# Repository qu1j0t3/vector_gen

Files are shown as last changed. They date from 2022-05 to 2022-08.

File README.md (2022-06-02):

# Vector generator

Copyright (C) 2017-2022 Toby Thain <toby@telegraphics.com.au>

## Purpose

This circuit is designed to produce X, Y and Z (blanking) signals
for an analog CRT such as an oscilloscope or XY monitor.

It is controlled by a microcontroller using one digital input
and 12 digital outputs. The speed of the microcontroller is not
critical to the design; all timing critical functions are executed
in hardware.

## Output specifications

### Monitors tested

* Tektronix 602, 603, 604, 606

## Graphic capabilities

* Positioning to 12 bit precision
* Lines (approx 20,000 short-medium vectors per second[1];
  10,000 "long" vectors per second[2])
  - dashed lines (dashing defined by 30 bit vector)
  - speed can be increased further by adjusting integrator passives
    and software optimisations
* Points (37,000-60,000 per second at 0.6µs dwell;
  variable brightness by adjusting dwell time)

[1] "boxes" benchmark
[2] "square" benchmark

Above figures assume:
- integrator input resistor 15 kOhm (this can be decreased, e.g. 4.7kOhm)
- integrator capacitor 10nF
- maximum slew rate approx 0.015 V/µs or draw full deflection in 66µs

## Microcontroller options

Dev board with Arduino Uno pinout. Pins provided for 5V inputs
or level shifted 3.3V inputs.

### Tested ports

* NXP Freedom KE06Z modified for 5V

### Planned ports

* Arduino Duemilanove, Uno
* STM32G474RE (3.3V)
* Adafruit M4 Express

## Power supply

Bipolar +5/-5V. Current approx 30mA (15mA excluding power LED).

Suitable supply from AC mains is Dura Micro MD5122-A1.

## Principle of operation

## Output examples/demos

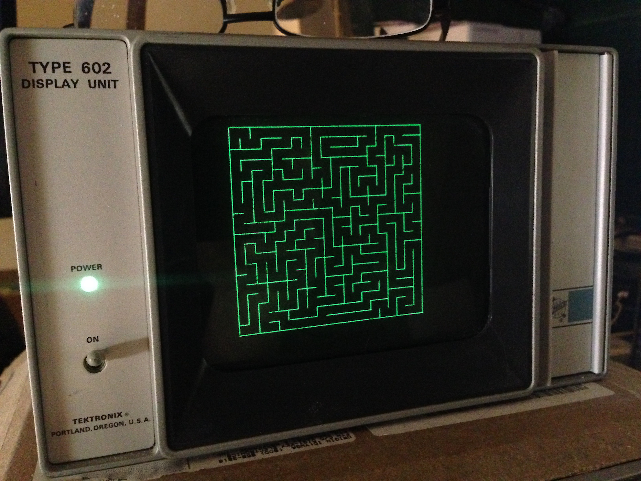
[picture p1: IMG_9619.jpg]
Maze displayed on Tektronix 602


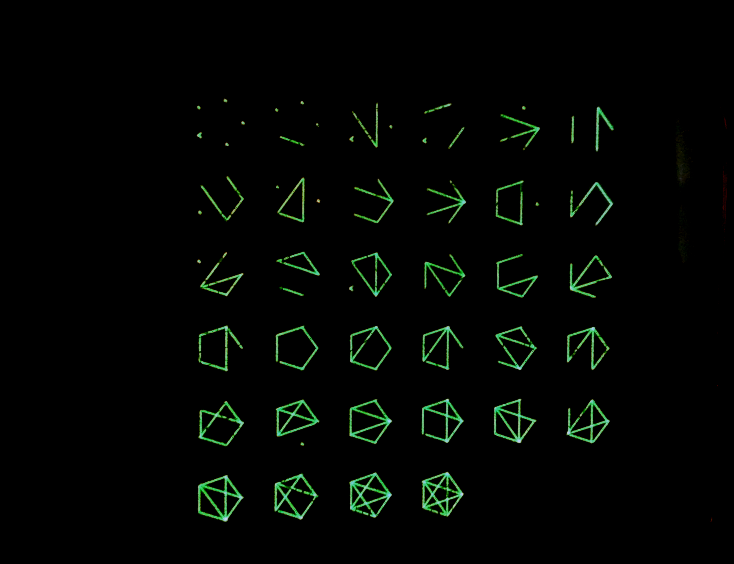
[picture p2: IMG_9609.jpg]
Graph enumerations displayed on Tektronix 602


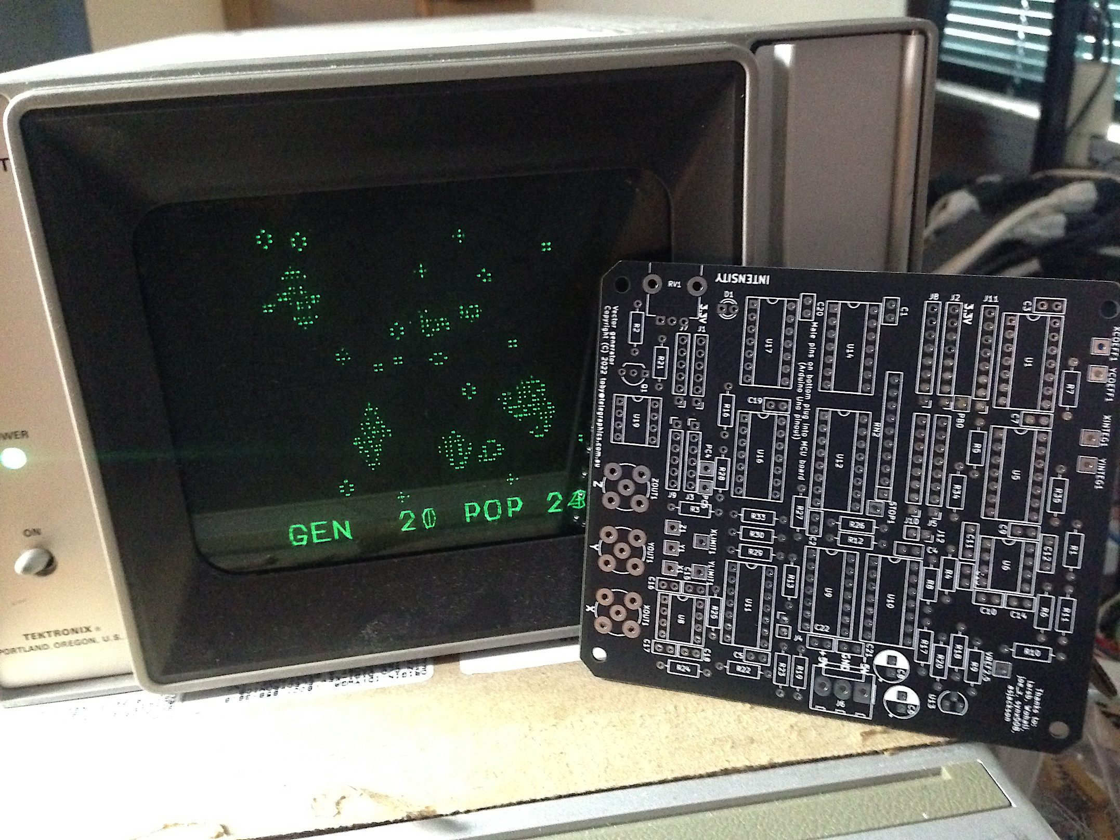
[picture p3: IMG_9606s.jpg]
Game of Life displayed on Tektronix 602, along with blank pcb


Dashed random line demo displayed on Tektronix 602

## Modifications

## Other applications

## Version history

* The first version of the board was produced in a batch of 5 by JLCPCB,
  May 2022. These were all claimed by friends and supporters
  even before the PCBs were delivered.

Original design was conceived in 2017/18.

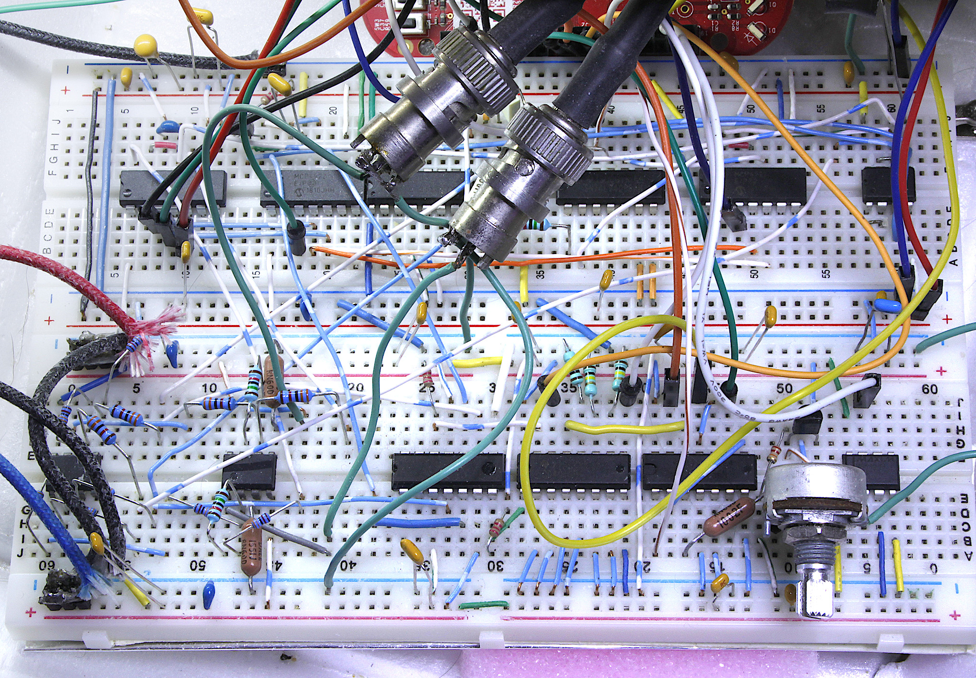
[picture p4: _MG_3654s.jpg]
Breadboard close to first PCB version


## Future plans

## Credits

I had assistance from many people, mostly via irc, including:

* `joe_z` & `Wohali` with far greater analog expertise
* `larsb`, who encouraged me to build this as an avenue for using real
  vector displays with software emulators of historical computers
* `asjackson`, fellow hacker and friend
* `genii`, who drilled many holes to work around a position defect
  on the first PCB version

## Dedication

Dedicated to my friend `bootnecklad`, 1995–2018.

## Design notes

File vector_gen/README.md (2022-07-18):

# Board assembly

## General

- Test points can be installed as needed;
  1.2mm holes suit Digikey 36-4952-ND
- IC orientations are consistent, pin 1 to left looking at front
  with power connection at right.

## Power

- Modular power supply is +5/-5V, Dura Micro MD5122-A1
- Connector J6
- R2: 330R or 270R
- LED D1
- test with +5V & GND on J6
- C6, C8: 100µF electrolytic

## Voltage reference

- U13 LM336
- R1 2.2k
- with power applied, check VREF2.5 test point

## 5V MCU

- install J7, J8, J9, J10
  - Only the 2 GND pins need be soldered for J7

## 3.3V MCU

- install J1, J2, J3, J5
  - Only the 2 GND pins need be soldered for J1
- install U16, U17 level shifting buffers
- install their decoupling caps C19, C20
- install RN2, R29, R30, R33, R3, R28

## Coefficient DACs

- install U1 MCP4922
- check levels with step voltage program (Test 1)

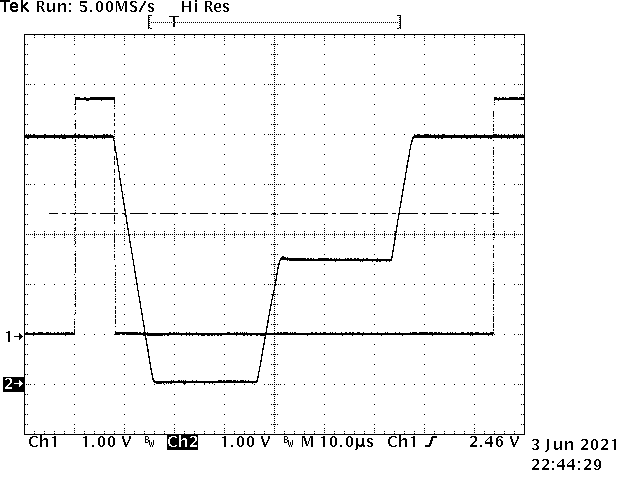
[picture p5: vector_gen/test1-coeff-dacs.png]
Test 1 - Coefficient DACs


## Integrators

- install U6 - tested with MCP6292
  - needs to be R2R output at least, does not need to be fast, as slew rates are < 0.05V/µs
- caps C11 and C12 must be matched closely.
  - I use an RC Schmitt oscillator and frequency counter to get relative values,
    sort, and take closest pairs.
- install R5, R7
  - these should be closely matched
  - tested between 4.7k (fast) and 15k (slow); should work even faster
    but with more timing error and noise susceptibility (I think)
- install R4, R6

## PCB version 1 bugs

In first version of PCB there is a bug that leaves U6 Vss/Vdd pins floating
and U5 Vdd floating:

- install jumper instead of C10, this connects U6 Vdd to GND
- install C9, and wire between +5V pin of C9 and +5V rail,
  e.g. + pin of C6, or +5V pin of power inlet connector.

Due to redrilling of X and Z BNC footprints:

- Z signal pin should be connected to pin 2 of U19 (analog switch)
  - This can be a wire, or for short circuit protection of the switch,
    a resistor at least 1k. The switch has a current limit of 10mA.
- Z signal pin should also be connected to Z1 test point if needed
- X signal pin should be connected to pin 1 of U8 (output amplifier)

## Switches

- install U5 SN74LV4066AN
- install R34, R35 47R - current limiting resistors
- check integrator run and reset with test program (Test program 2)

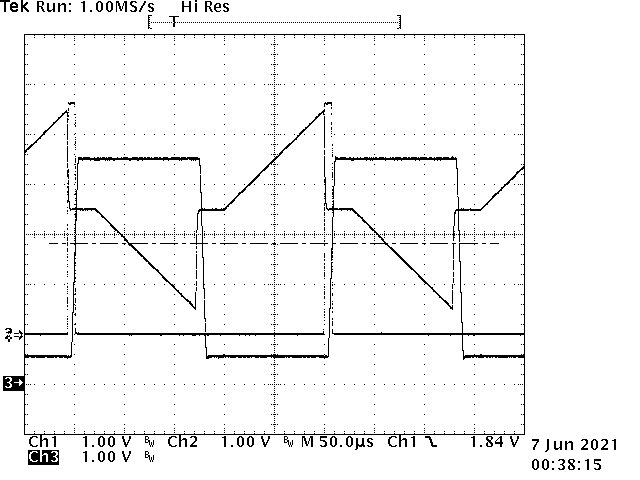
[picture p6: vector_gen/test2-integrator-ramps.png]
Test 2 - Integrators


## Rest of assembly

- R21: 22k 5%, Z output follower emitter resistor
- R26, R27: 2.2k 5%, pullups for comparators
- Q1: 2N3904 Z follower
- R12, R13: do not install unless needed - provides hysteresis to comparators. Nominal 100kOhm
- C13, C14, C17, C18: Vref filter caps - 1µF but could be increased to 4.7µF later?
- R16: 10kOhm Z divider
- C22, C21, C15, C16, C3, C4, C5, C7, C9, C1, C2: 1µF decoupling caps
- R8, R22: Matched pair which divide Vref to a position offset voltage, can be 15k or 33k
  - In fact the matching doesn't matter very much since the position is user adjustable on the monitor
  - This divider could be a pot if a position adjustment were desired on this board
- R10, R23: Same
- R9, R11: Do not install
- R17, R18: 33k, pair with matched values
- R24: arbitrary 15k
- R19, R20: 33k, pair with matched values
- R25: 15k selected so that ratio of R25 : (R19+R20) closely matches ratio of R24 : (R17+R18)
  - this should make the X and Y gain roughly equal
- install U8 TL072IP summing/output amplifiers
- install U9 LM319 limit comparators
- install U10 MCP4922 position DACs
- install U11 MCP4922 limit DACs
- install U12 CD4019BE AND/OR select
- install U14 74AHC86 quad XOR
- install U19 MAX4544 Z enable switch

## Calibration

### Test 1b - X/Y coefficient zero

* attach ground probe to a ground point on circuit,
  e.g. BNC shroud, or grounded pins of J1 (pins 2, 3 where pin 1 is closest to J3)
* after letting circuit warm up a few minutes, measure the 2.5V reference. e.g. VREF = 2.4897
* run test program 1b (see `main.c`)
* voltages should step through
  * XCOEFF expected: 2.5    actual: 2.4947 (XC)
  * YCOEFF expected: 2.5    actual: 2.4840 (YC)
* note actual voltages above, take differences from VREF, convert to DAC units
  * Noting that Coeff DACS use gain x2 i.e. 1 unit = 5/4096 V
  * XCOEFF adjustment is VREF-XC = 4096*(2.4897-2.4947)/5 = -4
  * YCOEFF adjustment is VREF-YC = 4096*(2.4897-2.4840)/5 = +5
  * Set these values in `display_list.h`, defines `DAC_COEFF_X_ADJ` and `DAC_COEFF_Y_ADJ`

### Test 3 - Z voltage

- Connect DVM ground to ground point (see test 1b)
- Connect DVM + lead to Z test point (if using first version pcb make sure it's connected, see bugs above)
- Run test program 3
- Turn Intensity pot fully CCW, voltage reads 1.628 (measured at pin 1 of U19)
  - at Z output this reads 1.978
- Turn fully CW, voltage reads approx zero
  - at Z output reads approx zero

### Test 4 - Limit DAC offsets - IMPORTANT

- Run test program 4
- Connect DVM ground to ground point (see test 1b)
- Connect DVM + lead to XINTEG test point, measure voltage, e.g. 2.4894 (XI)
- Move DVM + lead to YINTEG test point, measure voltage, e.g. 2.4900 (YI)
- Move DVM + lead to XLIMIT test point, measure voltage, e.g. 2.4955 (XL)
- Move DVM + lead to YLIMIT test point, measure voltage, e.g. 2.5054 (YL)
- Noting that Limit DACS use gain x2 i.e. 1 unit = 5/4096 V
- Compute limit adjustment for X = 4096*(XI - XL)/5 = -5
- adjustment for Y = 4096*(YI - YL)/5 = -13
- Set these values in `display_list.h`, defines `DAC_LIMIT_X_ADJ` and `DAC_LIMIT_Y_ADJ`

- Run test program 4b
- Check that XLIMIT and YLIMIT are within about 2 mV of XINTEG and YINTEG

## Version 2

- add [supply reversal protection](https://twitter.com/gsuberland/status/1348719603799773189)

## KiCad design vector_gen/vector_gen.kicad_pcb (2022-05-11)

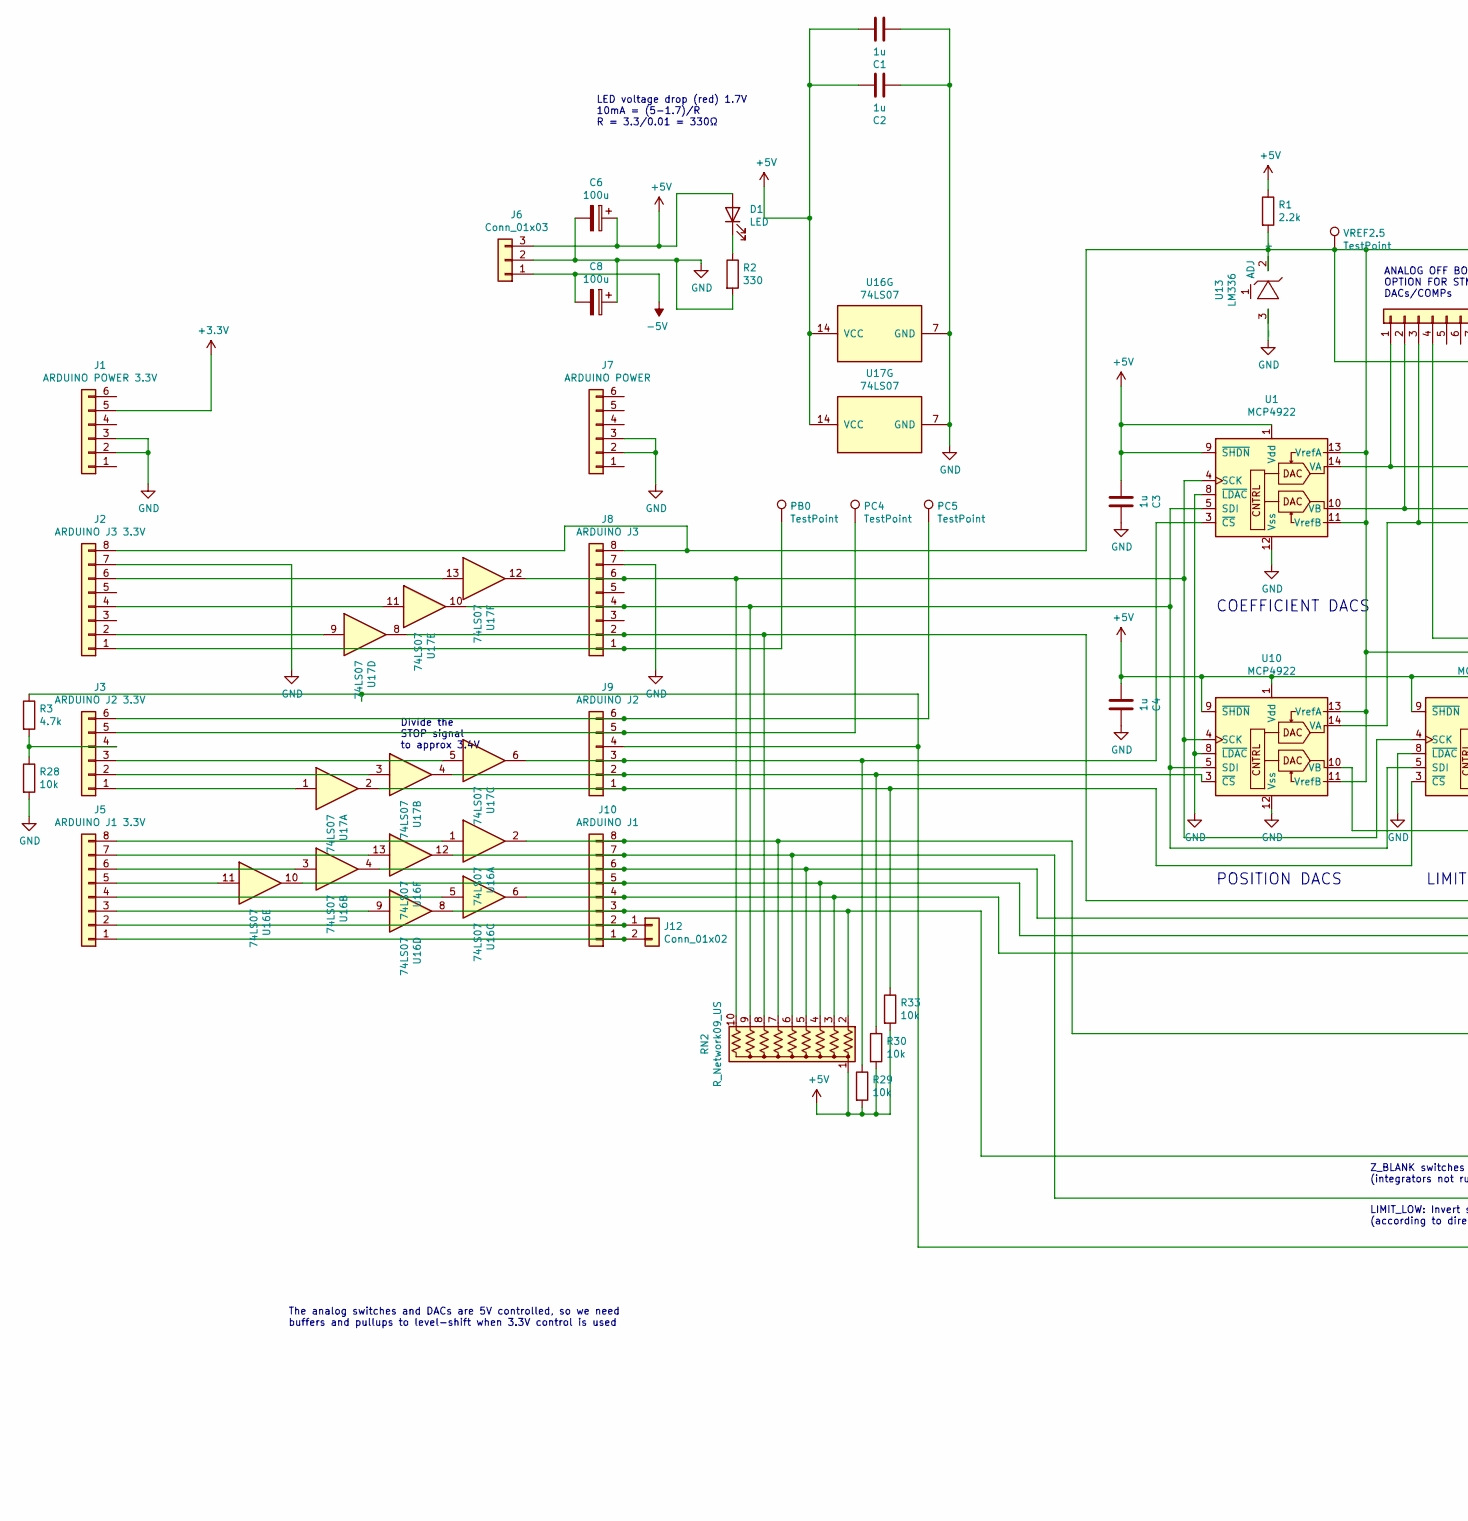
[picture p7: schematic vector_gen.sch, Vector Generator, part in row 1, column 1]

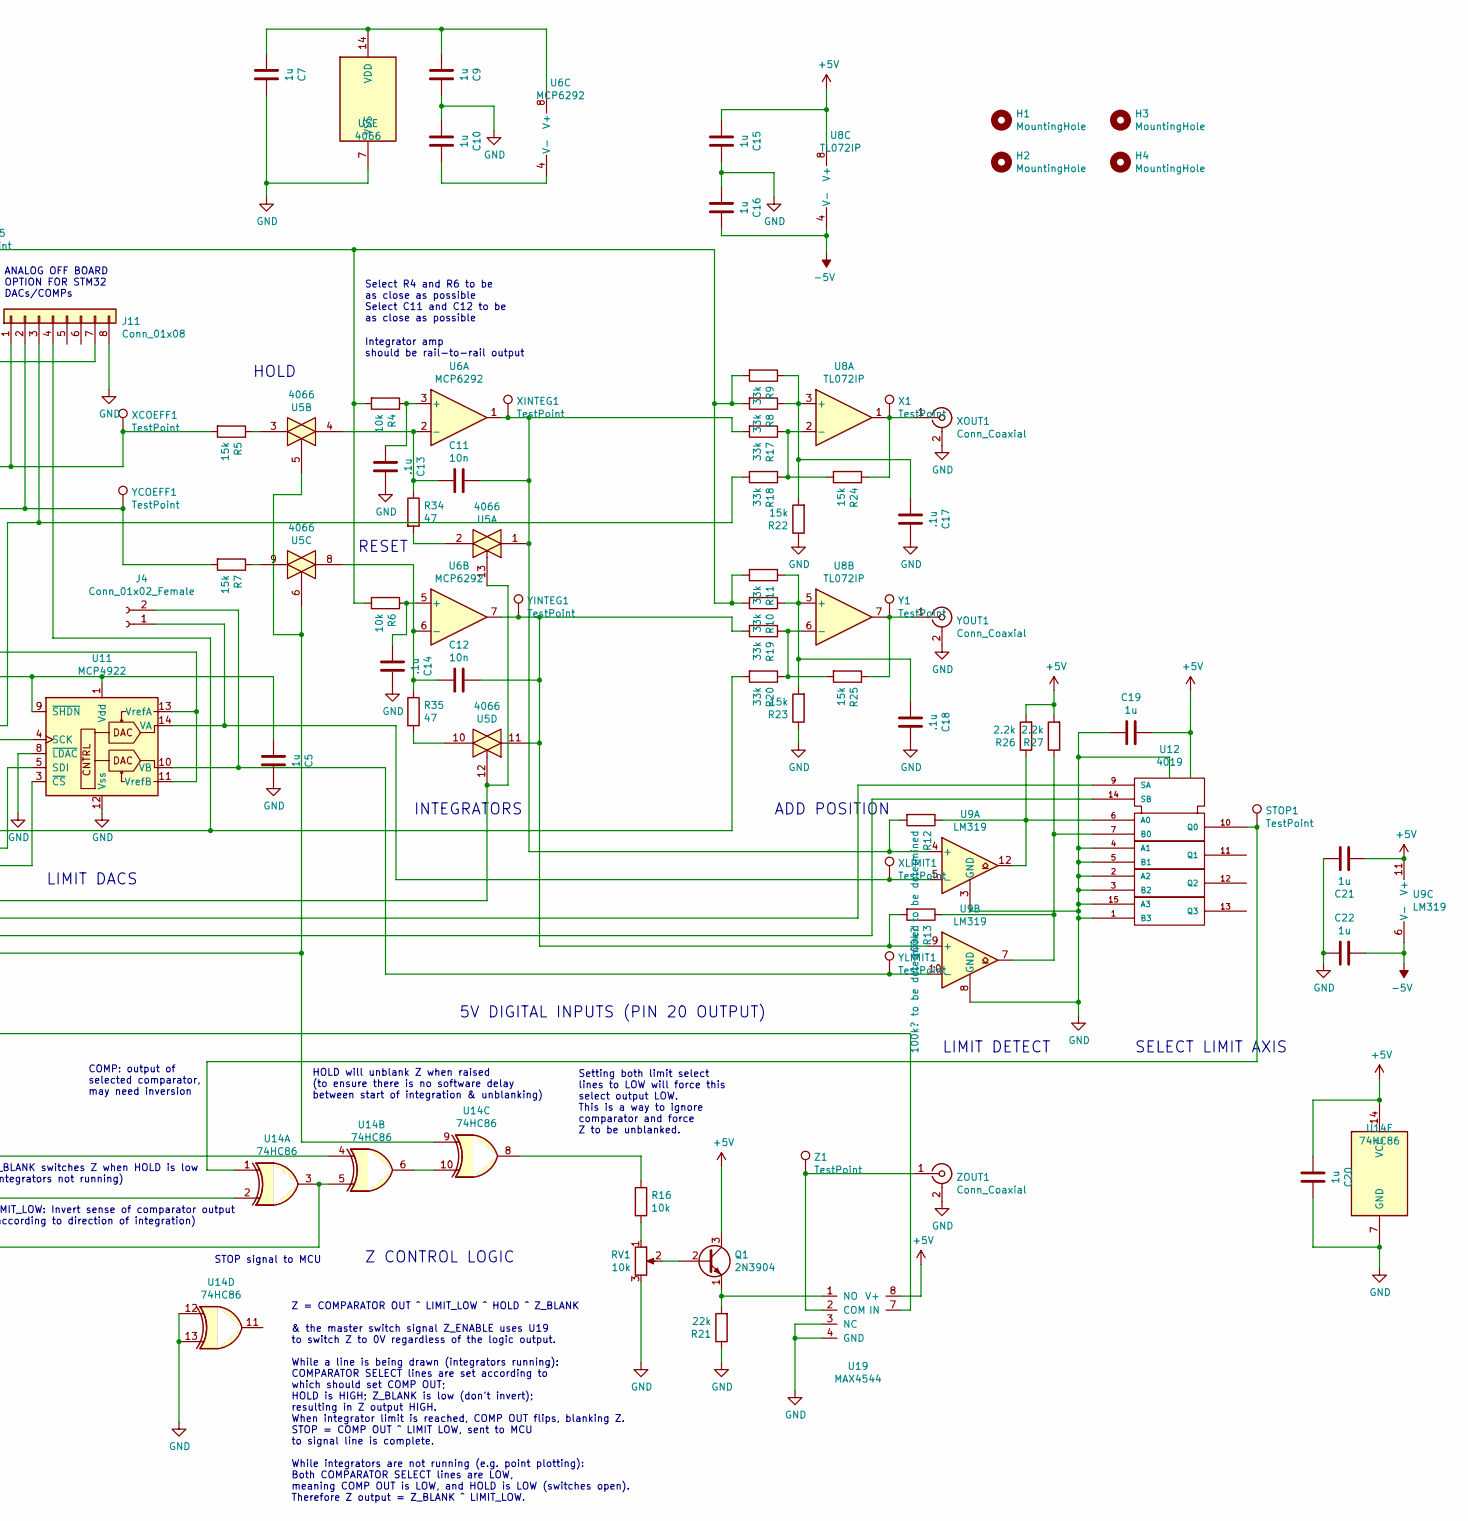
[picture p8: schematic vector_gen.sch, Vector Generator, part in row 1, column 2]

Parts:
C1, C2, C3, C4, C5, C7, C9, C10, C15, C16, C19, C20, C21, C22: 1u; C_Disc_D5.0mm_W2.5mm_P2.50mm
C6, C8: 100u; CP_Radial_D6.3mm_P2.50mm
C11, C12: 10n; C_Rect_L7.0mm_W2.5mm_P5.00mm
C13, C14, C17, C18: .1u; C_Disc_D5.0mm_W2.5mm_P2.50mm
D1: LED; LED_D3.0mm
H1, H2, H3, H4: MountingHole; MountingHole_3.2mm_M3
J1: ARDUINO POWER 3.3V; PinHeader_1x06_P2.54mm_Vertical
J2: ARDUINO J3 3.3V; PinHeader_1x08_P2.54mm_Vertical
J3: ARDUINO J2 3.3V; PinHeader_1x06_P2.54mm_Vertical
J4: Conn_01x02_Female; PinHeader_1x02_P2.54mm_Vertical
J5: ARDUINO J1 3.3V; PinHeader_1x08_P2.54mm_Vertical
J6: Conn_01x03; Molex_KK-396_A-41791-0003_1x03_P3.96mm_Vertical
J7: ARDUINO POWER; PinHeader_1x06_P2.54mm_Vertical
J8: ARDUINO J3; PinHeader_1x08_P2.54mm_Vertical
J9: ARDUINO J2; PinHeader_1x06_P2.54mm_Vertical
J10: ARDUINO J1; PinHeader_1x08_P2.54mm_Vertical
J11: Conn_01x08; PinHeader_1x08_P2.54mm_Vertical
J12: Conn_01x02; PinSocket_1x02_P2.54mm_Vertical
PB0: TestPoint; TestPoint_THTPad_2.5x2.5mm_Drill1.2mm
PC4, PC5: TestPoint; TestPoint_THTPad_2.5x2.5mm_Drill1.2mm
Q1: 2N3904; TO-92_Inline_Wide
R1, R26, R27: 2.2k; R_Axial_DIN0207_L6.3mm_D2.5mm_P10.16mm_Horizontal
R2: 330; R_Axial_DIN0207_L6.3mm_D2.5mm_P10.16mm_Horizontal
R3: 4.7k; R_Axial_DIN0207_L6.3mm_D2.5mm_P10.16mm_Horizontal
R4, R6, R16, R28, R29, R30, R33: 10k; R_Axial_DIN0207_L6.3mm_D2.5mm_P10.16mm_Horizontal
R5, R7, R22, R23, R24, R25: 15k; R_Axial_DIN0207_L6.3mm_D2.5mm_P10.16mm_Horizontal
R8, R9, R10, R11, R17, R18, R19, R20: 33k; R_Axial_DIN0207_L6.3mm_D2.5mm_P10.16mm_Horizontal
R12, R13: 100k? to be determined; R_Axial_DIN0207_L6.3mm_D2.5mm_P10.16mm_Horizontal
R21: 22k; R_Axial_DIN0207_L6.3mm_D2.5mm_P10.16mm_Horizontal
R34, R35: 47; R_Axial_DIN0207_L6.3mm_D2.5mm_P10.16mm_Horizontal
RN2: R_Network09_US; R_Array_SIP10
RV1: 10k; Potentiometer_TT_P0915N
STOP1: TestPoint; TestPoint_THTPad_2.5x2.5mm_Drill1.2mm
U1, U10, U11: MCP4922; DIP-14_W7.62mm_Socket
U5: 4066; DIP-14_W7.62mm_Socket
U6: MCP6292; DIP-8_W7.62mm_Socket
U8: TL072IP; DIP-8_W7.62mm_Socket
U9: LM319; DIP-14_W7.62mm_Socket
U12: 4019; DIP-16_W7.62mm_Socket
U13: LM336; TO-92_HandSolder
U14: 74HC86; DIP-14_W7.62mm_Socket
U16, U17: 74LS07; DIP-14_W7.62mm_Socket
U19: MAX4544; DIP-8_W7.62mm_Socket
VREF2.5: TestPoint; TestPoint_THTPad_2.5x2.5mm_Drill1.2mm
X1: TestPoint; TestPoint_THTPad_2.5x2.5mm_Drill1.2mm
XCOEFF1: TestPoint; TestPoint_THTPad_2.5x2.5mm_Drill1.2mm
XINTEG1: TestPoint; TestPoint_THTPad_2.5x2.5mm_Drill1.2mm
XLIMIT1: TestPoint; TestPoint_THTPad_2.5x2.5mm_Drill1.2mm
XOUT1: Conn_Coaxial; BNC_TEConnectivity_1478204_Vertical
Y1: TestPoint; TestPoint_THTPad_2.5x2.5mm_Drill1.2mm
YCOEFF1: TestPoint; TestPoint_THTPad_2.5x2.5mm_Drill1.2mm
YINTEG1: TestPoint; TestPoint_THTPad_2.5x2.5mm_Drill1.2mm
YLIMIT1: TestPoint; TestPoint_THTPad_2.5x2.5mm_Drill1.2mm
YOUT1: Conn_Coaxial; BNC_TEConnectivity_1478204_Vertical
Z1: TestPoint; TestPoint_THTPad_2.5x2.5mm_Drill1.2mm
ZOUT1: Conn_Coaxial; BNC_TEConnectivity_1478204_Vertical

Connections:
+3V3: J1.5
+5V: C1.1, C2.1, C3.2, C4.2, C5.2, C6.1, C15.2, C19.1, C20.2, C21.2, D1.2 (A), J6.3, Q1.3 (C), R1.1, R26.2, R27.2, R29.2, R30.2, R33.2, RN2.1 (common), U1.1 (Vdd), U1.9 (~SHDN), U8.8 (V+), U9.11 (V+), U10.1 (Vdd), U10.9 (~SHDN), U11.1 (Vdd), U11.9 (~SHDN), U12.16 (Vdd), U14.14 (VCC), U16.14 (VCC), U17.14 (VCC), U19.8 (V+)
-5V: C8.2, C16.1, C22.1, J6.1, U8.4 (V-), U9.6 (V-)
GND: C1.2, C2.2, C3.1, C4.1, C5.1, C6.2, C7.1, C8.1, C9.1, C10.2, C13.1, C14.1, C15.1, C16.2, C17.1, C18.1, C19.2, C20.1, C21.1, C22.2, J1.2, J1.3, J2.7, J6.2, J7.2, J7.3, J8.7, J11.8, R2.2, R21.1, R22.1, R23.1, R28.2, RV1.3, U1.8 (~LDAC), U1.12 (Vss), U5.7 (VSS), U9.3 (GND), U9.8 (GND), U10.8 (~LDAC), U10.12 (Vss), U11.8 (~LDAC), U11.12 (Vss), U12.1 (B3), U12.2 (A2), U12.3 (B2), U12.4 (A1), U12.5 (B1), U12.8 (Vss), U12.15 (A3), U13.3 (-), U14.7 (GND), U14.12, U14.13, U16.7 (GND), U17.7 (GND), U19.3 (NC), U19.4 (GND), XOUT1.2 (Ext), YOUT1.2 (Ext), ZOUT1.2 (Ext)
unnamed: C7.2, C9.2, U5.14 (VDD), U6.8 (V+)
unnamed: C10.1, U6.4 (V-)
unnamed: C11.1, R12.2, R17.2, U5.1, U6.1, U9.4 (+), XINTEG1.1
unnamed: C11.2, R34.1, U5.4, U6.2 (-)
unnamed: C12.1, R13.2, R19.2, U5.11, U6.7, U9.9 (+), YINTEG1.1
unnamed: C12.2, R35.1, U5.8, U6.6 (-)
unnamed: C13.2, R4.1, U6.3 (+)
unnamed: C14.2, R6.1, U6.5 (+)
unnamed: C17.2, R8.1, R9.1, R22.2, U8.3 (+)
unnamed: C18.2, R10.1, R11.1, R23.2, U8.5 (+)
unnamed: D1.1 (K), R2.1
unnamed: J2.1, J8.1, PB0.1
unnamed: J2.2, U17.9
unnamed: J2.4, U17.11
unnamed: J2.6, U17.13
unnamed: J3.1, U17.1
unnamed: J3.2, U17.3
unnamed: J3.3, U17.5
unnamed: J3.4, R3.2, R28.1
unnamed: J3.5, J9.5, PC4.1
unnamed: J3.6, J9.6, PC5.1
unnamed: J4.1, U9.5 (-), U11.14 (VA), XLIMIT1.1
unnamed: J4.2, U9.10 (-), U11.10 (VB), YLIMIT1.1
unnamed: J5.3, U16.9
unnamed: J5.4, U16.5
unnamed: J5.5, U16.11
unnamed: J5.6, U16.3
unnamed: J5.7, U16.13
unnamed: J5.8, U16.1
unnamed: J8.2, RN2.8 (R7), U5.12, U5.13, U17.8
unnamed: J8.4, RN2.9 (R8), U1.5 (SDI), U10.5 (SDI), U11.5 (SDI), U17.10
unnamed: J8.6, RN2.10 (R9), U1.4 (SCK), U10.4 (SCK), U11.4 (SCK), U17.12
unnamed: J9.1, R33.1, U11.3 (~CS), U17.2
unnamed: J9.2, R30.1, U10.3 (~CS), U17.4
unnamed: J9.3, R29.1, U1.3 (~CS), U17.6
unnamed: J9.4, R3.1, U14.3, U14.5
unnamed: J5.1, J10.1, J12.2
unnamed: J5.2, J10.2, J12.1
unnamed: J10.3, RN2.2 (R1), U14.4, U16.8
unnamed: J10.4, RN2.3 (R2), U5.5, U5.6, U14.9, U16.6
unnamed: J10.5, RN2.4 (R3), U12.14 (SB), U16.10
unnamed: J10.6, RN2.5 (R4), U12.9 (SA), U16.4
unnamed: J10.7, RN2.6 (R5), U14.2, U16.12
unnamed: J10.8, RN2.7 (R6), U16.2, U19.7 (IN)
unnamed: J11.1, R5.2, U1.14 (VA), XCOEFF1.1
unnamed: J11.2, R7.2, U1.10 (VB), YCOEFF1.1
unnamed: J11.3, R18.2, U10.14 (VA)
unnamed: J11.4, R20.2, U10.10 (VB)
unnamed: J2.8, J8.8, J11.7, R1.2, R4.2, R6.2, R8.2, R9.2, R10.2, R11.2, U1.11 (VrefB), U1.13 (VrefA), U10.11 (VrefB), U10.13 (VrefA), U11.11 (VrefB), U11.13 (VrefA), U13.2 (+), VREF2.5.1
unnamed: Q1.1 (E), R21.2, U19.1 (NO)
unnamed: Q1.2 (B), RV1.2
unnamed: R5.1, U5.3
unnamed: R7.1, U5.9
unnamed: R12.1, R26.1, U9.12, U12.6 (A0)
unnamed: R13.1, R27.1, U9.7, U12.7 (B0)
unnamed: R16.1, U14.8
unnamed: R16.2, RV1.1
unnamed: R17.1, R18.1, R24.2, U8.2 (-)
unnamed: R19.1, R20.1, R25.2, U8.6 (-)
unnamed: R24.1, U8.1, X1.1, XOUT1.1 (In)
unnamed: R25.1, U8.7, Y1.1, YOUT1.1 (In)
unnamed: R34.2, U5.2
unnamed: R35.2, U5.10
unnamed: STOP1.1, U12.10 (Q0), U14.1
unnamed: U14.6, U14.10
unnamed: U19.2 (COM), Z1.1, ZOUT1.1 (In)

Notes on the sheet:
Select R4 and R6 to be as close as possible Select C11 and C12 to be as close as possible
Integrator amp should be rail-to-rail output
COEFFICIENT DACS
ANALOG OFF BOARD OPTION FOR STM32 DACs/COMPs
5V DIGITAL INPUTS (PIN 20 OUTPUT)
RESET
HOLD
Setting both limit select lines to LOW will force this select output LOW. This is a way to ignore comparator and force Z to be unblanked.
SELECT LIMIT AXIS
LIMIT DETECT
ADD POSITION
INTEGRATORS
LIMIT DACS
POSITION DACS
LIMIT_LOW: Invert sense of comparator output (according to direction of integration)
HOLD will unblank Z when raised (to ensure there is no software delay between start of integration & unblanking)
STOP signal to MCU
Z_BLANK switches Z when HOLD is low (integrators not running)
Z = COMPARATOR OUT ^ LIMIT_LOW ^ HOLD ^ Z_BLANK & the master switch signal Z_ENABLE uses U19 to switch Z to 0V regardless of the logic output. While a line is being drawn (integrators running): COMPARATOR SELECT lines are set according to which should set COMP OUT; HOLD is HIGH; Z_BLANK is low (don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
Z CONTROL LOGIC
The analog switches and DACs are 5V controlled, so we need buffers and pullups to level-shift when 3.3V control is used
Divide the STOP signal to approx 3.4V
COMP: output of selected comparator, may need inversion
LED voltage drop (red) 1.7V 10mA = (5-1.7)/R R = 3.3/0.01 = 330Ω

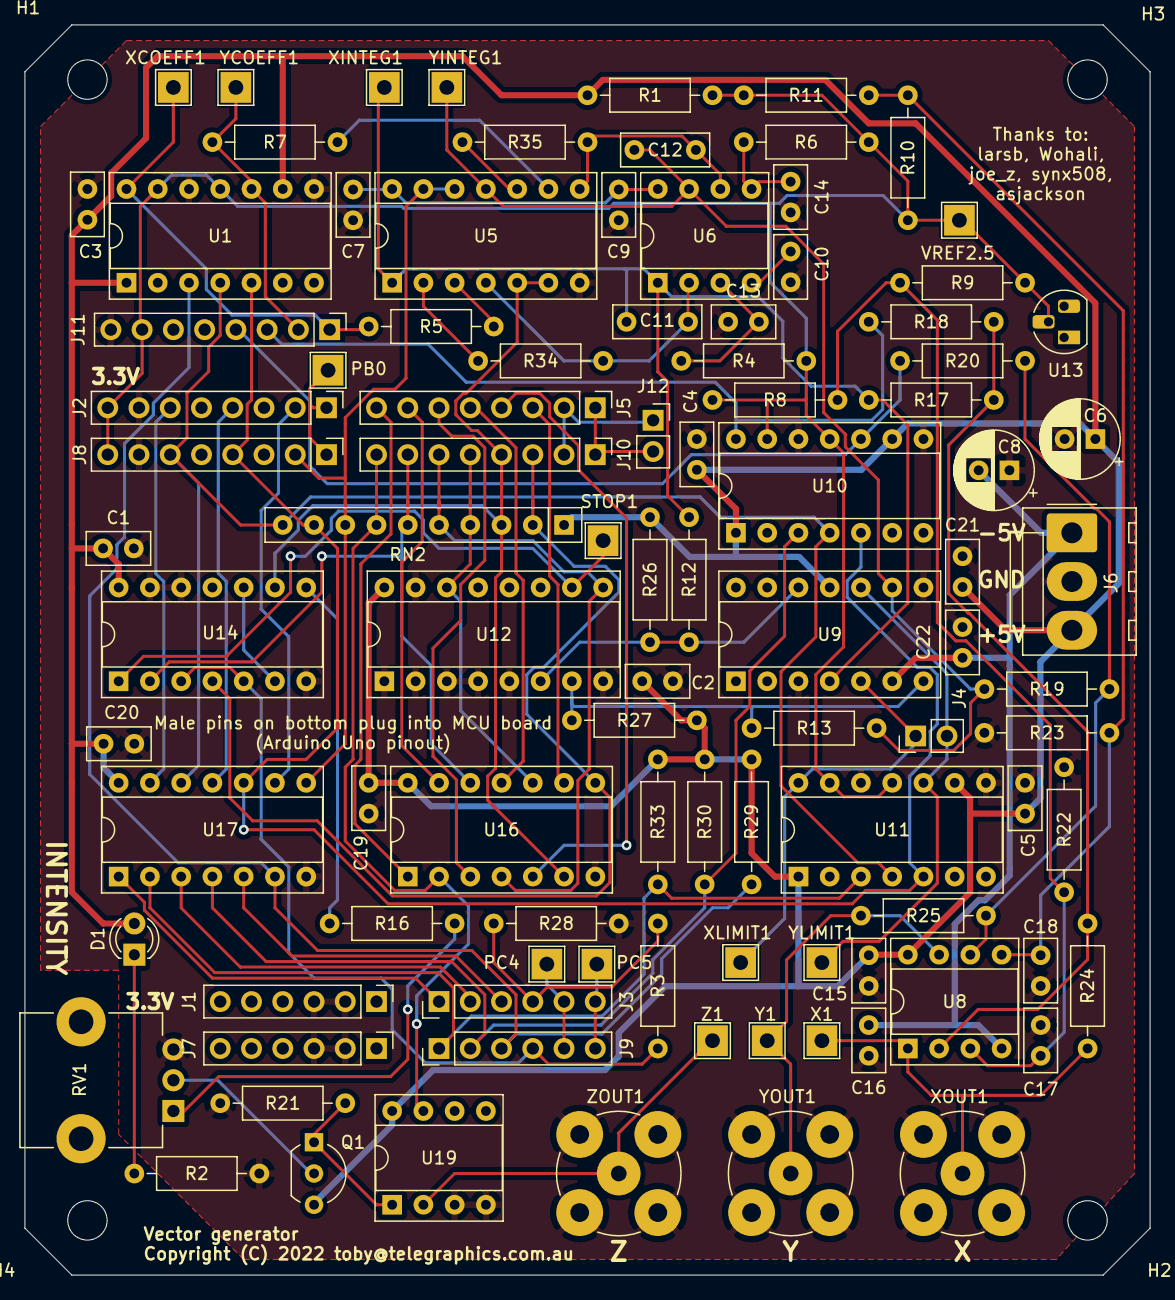
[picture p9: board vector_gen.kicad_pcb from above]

Board: 2 copper layers, 91.4 x 101.6 mm, 103 parts (0 on the bottom side), 69 nets.

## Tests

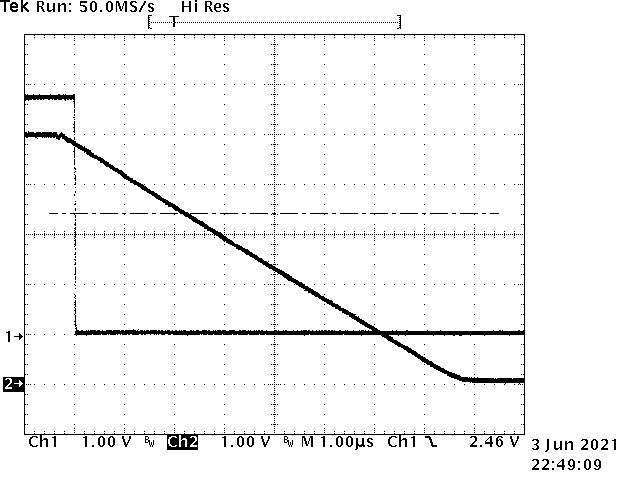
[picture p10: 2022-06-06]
vector_gen/test1-1us-div.png

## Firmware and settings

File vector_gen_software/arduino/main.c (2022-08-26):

/*
    This file is part of the Vector Generator project for drawing analogue
    graphics on X/Y oscilloscopes.

    Copyright (C) 2018-2022 Toby Thain, toby@telegraphics.com.au

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
    You should have received a copy of the GNU General Public License
    along with this program; if not, write to the Free Software
    Foundation, Inc., 59 Temple Place, Suite 330, Boston, MA  02111-1307  USA
*/

// Driver software for vector generator board
// Arduino version


#include <avr/io.h>
#include <util/delay.h>

#include "hw_impl.h"
#include "../portable/tests.h"
#include "../portable/hardware.h"
#include "../portable/demos.h"


int main (void)
{
  hw_setup();

  uart_init();

  while(0) test1();

  //demo_maze();
  //demo_boxes(); // includes interactive Limit DAC calibration through serial port
  //demo_square();
  //demo_rocks();
  demo_starburst();

  return 1;
}

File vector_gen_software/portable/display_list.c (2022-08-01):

/*
    This file is part of the Vector Generator project for drawing analogue
    graphics on X/Y oscilloscopes.

    Copyright (C) 2018-2022 Toby Thain, toby@telegraphics.com.au

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
    You should have received a copy of the GNU General Public License
    along with this program; if not, write to the Free Software
    Foundation, Inc., 59 Temple Place, Suite 330, Boston, MA  02111-1307  USA
*/

#include <stdint.h>
#include <stdlib.h>

#include "display_list.h"
#include "isqrt.h"
#include "hardware.h"

#include "hw_impl.h"

#define NORMALISE_DIRECTIONS 0
#define VARIABLE_SETTLING 0  // need to benchmark this

// If FRAME_SYNC is 1, then the execution of the display list
// will wait until at least one PIT tick has elapsed (see init code),
// producing a frame rate that is somewhat decoupled from
// the size of the display list

#define FRAME_SYNC 0

// Dash styles are defined as a vector of six bits
// that repeat along the line
uint8_t line_dash_style[] = {
		0,
		0b001001,
		0b000111,
		0b011111
};

int8_t dac_limit_x_adj = DAC_LIMIT_X_ADJ;
int8_t dac_limit_y_adj = DAC_LIMIT_Y_ADJ;

uint8_t ptx[COARSE_POINT_MAX], pty[COARSE_POINT_MAX];

#define END_OBJECT(line)     (line->flags & END_OBJECT_MASK)
#define LINE_LIMIT_X(line)   (line->flags & LINE_LIMIT_X_MASK)
#define LINE_LIMIT_LOW(line) (line->flags & LINE_LIMIT_LOW_MASK)
#define LINE_ACTIVE(line)    (line->flags & LINE_ACTIVE_MASK)
#define IS_POINT(line)       (line->flags & IS_POINT_MASK)

volatile uint32_t ticks;

/*
int compar_func(const void *pa, const void *pb) {
	uint16_t a = *(const uint16_t*)pa;
	uint16_t b = *(const uint16_t*)pb;

	// sort lines left to right by X starting position
	int sign = (pos_dac_x[a] & 0xfff) - (pos_dac_x[b] & 0xfff);
	return sign ? sign : (
		// Then sort by Y
		(pos_dac_y[a] & 0xfff) - (pos_dac_y[b] & 0xfff)
	);
}

void sort_display_list(uint16_t count, uint16_t perm[]) {
	qsort(perm, count, sizeof(perm[0]), compar_func);
}

void shuffle_display_list(uint16_t count, uint16_t perm[]) {
	for(unsigned n = count; n > 1;) {
		unsigned chosen = (uint16_t)rand() % n;
		--n;
		uint16_t temp = perm[n];
		perm[n] = perm[chosen];
		perm[chosen] = temp;
	}
}
*/

/*
 * Parameters:  x0, y0, x1, y1 : line endpoints; range from -2047 to +2048
 *              dash           : 30 bits of dash pattern; zero for solid line
 */

uint8_t setup_line_int_(struct line *line, int16_t x0, int16_t y0, int16_t x1, int16_t y1, uint8_t dash) {

	int16_t dx = x1-x0, dy = y1-y0, posx, posy;

	// treat very short lines as points (since crt cannot resolve anyway)
	// can be calibrated using short lines test pattern below
	// at some point around length 7 units, lines start to lose brightness

	uint8_t line_limit_x = abs(dx) > abs(dy);

	int16_t larger_delta = line_limit_x ? dx : dy;

	uint8_t line_limit_low = larger_delta > 0;

	uint8_t is_point = larger_delta == 0;

	if (is_point) {
		posx = 2048 - (x0+x1)/2;
		posy = 2048 - (y0+y1)/2;
	} else {
		posx = 2048 - x0;
		posy = 2048 - y0;

		// DAC Datasheet output swing = typ 0.01 to Vdd-0.04
		// When powered from USB, Vdd can swing as low as 4.53V-4.80V in my setup (usb hub with other devices connected)
		// i.e. 0.01 to 4.76 which is a scale of 0.952 x full range. (WORST case 0.898)
		// N.B. This is best verified by using the Starburst test below. When Vdd is too low,
		//      coefficient error near Vdd causes lines to meet and cross some distance from the centre of the pattern.
		//      When the full coefficient range is available, lines should meet close to the centre.

		// Update: Even when analog section is powered from a regulated 5V supply,
		//         0.9 x full scale is about the maximum we can do before beginning to hit nonlinearity.

		// Integrator Vin = max 2.25V above "zero"
		// R = 15kΩ   C = 10nF
		// dV/dt = 2.25 / (15000*0.00000001) V/second = 0.015 V/µs

    // premultiply the length denominator for a little more precision in the square root
		// max dx, dy: 4096 = 2^12; squared and summed: 2^25; then the scale factor must be < 6 bits!
		// choose the largest possible square scale factor of 64 and divisor of 7 i.e. 7/8 = 0.875
	  uint16_t len = isqrt(64*((int32_t)dx*dx + (int32_t)dy*dy));
		uint16_t xcf = 2048 + ((int32_t)dx*2047*7)/len;
		uint16_t ycf = 2048 + ((int32_t)dy*2047*7)/len;

		line->x_coeff = DAC_A | DAC_BUFFERED | DAC_GAINx2 | DAC_ACTIVE | (xcf+DAC_COEFF_X_ADJ);
		line->y_coeff = DAC_B | DAC_BUFFERED | DAC_GAINx2 | DAC_ACTIVE | (ycf+DAC_COEFF_Y_ADJ);

		// ** Important: The Limit DACs are not _absolute_ voltages,
		//               but are compared to integrator outputs.
		//               Integrator "zero" (i.e. start of line) is at 2.5v,
		//               or 2048 in Limit DAC input units.

		// We run the position DACs at gain x1 and the limit DACs at gain x2
		// so divide position delta by 2 to get the limit DAC input delta.

		// To ensure integration will stop even if the "delta" overflows,
		// we clamp the limit DAC output to the correct extreme.

		// TODO: Review this factor. With the MCP6292 I think I am seeing
		//       the integrators reach ~ +50mV before becoming nonlinear
		//       at a sharp "knee". (Check amp datasheet)
		#define LIMIT_DAC_MAX 2000

		uint16_t delta = (uint16_t)abs(larger_delta)/2;
		int16_t clamp;
		if (line_limit_low) {
			clamp = delta > LIMIT_DAC_MAX ? 0 : 2048 - delta;
		} else {
			clamp = delta > LIMIT_DAC_MAX ? 4095 : 2048 + delta;
		}

		// While the limit DAC can use almost the whole range between 0 and 5V (with integrator "zero" at 2.5V),
		// the integrators themselves cannot reach these limits. We therefore need to clamp the limit DAC
		// to a reduced, practical range, or the system will stop, waiting forever for a threshold that can't be reached.
		// In tests with LF412CP op amp, the integrators can rise to about 4V (+1.5V), and drop to about 1.3V (-1.2V).
		// With a different rail to rail amp, these limits can be increased.
		// FIXME: This range may not be enough! Because the scope is typically calibrated to 1V full deflection.
		// (As a failsafe, we might need a timeout as well.)
		// TODO: This can be self calibrating

		/* Update: Changed to MCP6292 op amp for integrator and removed the clamping.
		int32_t limit_max = (int32_t)( (4.95/5.0)*0xfffu );
		int32_t limit_min = (int32_t)( (0.05/5.0)*0xfffu );
		uint16_t clamped = limit; //(uint16_t)( limit < limit_min ? limit_min : (limit > limit_max ? limit_max : limit) );*/

		// The limit DAC may have an offset relative to position DAC,
		// which leads lines to overshoot or undershoot their limit.
		// Add a correction which can either be manually measured with DVM,
		// or self calibrated (TODO).

		if (line_limit_x) {
			clamp += dac_limit_x_adj;
			line->limit = (uint16_t)( DAC_A | DAC_BUFFERED | DAC_GAINx2 | DAC_ACTIVE | (uint16_t)clamp );
		} else {
			clamp += dac_limit_y_adj;
			line->limit = (uint16_t)( DAC_B | DAC_BUFFERED | DAC_GAINx2 | DAC_ACTIVE | (uint16_t)clamp );
		}
	}
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

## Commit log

2022-02-08 Initial commit with Kicad project.
    [vector_gen.kicad_pcb, vector_gen.sch]
2022-02-09 More additions.
    [vector_gen.sch]
2022-02-11 Update with analog option connector, power connector, etc.
    [vector_gen.sch]
2022-03-07 Replace Yamaha DACs with MCP4922 for coefficients.
    [vector_gen.sch]
2022-03-27 Snapshot of work in progress pcb.
    [vector_gen.kicad_pcb, vector_gen.sch]
2022-04-22 PCB almost routed.
    [vector_gen.kicad_pcb, vector_gen.sch]
2022-04-23 More routing.
    [vector_gen.kicad_pcb, vector_gen.sch]
2022-04-24 Rerrange layout
    [vector_gen.kicad_pcb, vector_gen.sch]
2022-04-28 Ground plane done?
    [vector_gen.kicad_pcb, vector_gen.sch]
2022-05-03 Add fill to front copper and suggestions from joe_z.
    [vector_gen.kicad_pcb, vector_gen.sch]
2022-05-03 Fix a connectivity issue.
    [vector_gen.kicad_pcb]
2022-05-08 Some important corrections. OSHpark candidate?
    [vector_gen.kicad_pcb, vector_gen.sch]
2022-05-09 New OSHPark manuf candidate.
    [vector_gen.kicad_pcb, vector_gen.sch]
2022-05-10 New manuf candidate.
    [vector_gen.kicad_pcb]
2022-05-11 Final JLPCB order.
    [vector_gen.kicad_pcb]
2022-05-29 SPI DAC working.
2022-06-02 Add pcb assembly notes.
2022-06-11 Assembly updates.
2022-06-17 WIP. Port to Arduino.
2022-07-18 Add test program and instructions for Limit DAC calibration.
2022-07-31 Work in progress on interrupt driven drawing.
2022-08-01 Tweak dashing code. Add serial port code and interactive DAC limit calibration (in 'boxes' demo).

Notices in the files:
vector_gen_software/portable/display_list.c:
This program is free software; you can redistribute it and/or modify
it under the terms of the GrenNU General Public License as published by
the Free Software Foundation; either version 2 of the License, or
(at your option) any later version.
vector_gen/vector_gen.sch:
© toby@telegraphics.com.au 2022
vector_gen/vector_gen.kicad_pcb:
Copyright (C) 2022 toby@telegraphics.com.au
